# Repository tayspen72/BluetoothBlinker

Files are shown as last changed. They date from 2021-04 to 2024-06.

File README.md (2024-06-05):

Objective:
The goal of the project is to help myself become more familiar with the electronics design process. This includes:
* Schematic Design
* Component Selection
* PCB Layout
* Initial Board Bring-Up and Verification
* Firmware Development
* Evaluate Rust in an embedded microcontroller application

Plan
Build a PCB project with a similar purpose to a manufacturer evalutation kit with the following requirements:
* Bluetooth connectivity
* IO available with _reasonable_ function through peripherals
* Connectible to PC using USB-C
* Logging through UART when connected to PC

Conclusion:
The board design was completed and peer reviewed (by coworker)
Samples were ordered through PCB way and digikey for components
Samples were hand assembled (with blood sweat and tears)
Issue in the inline fuse, replaced with 0R resistor to advance in design
Board is functional, able to program and toggle LED using available IO
Bluetooth connectivity is pending..

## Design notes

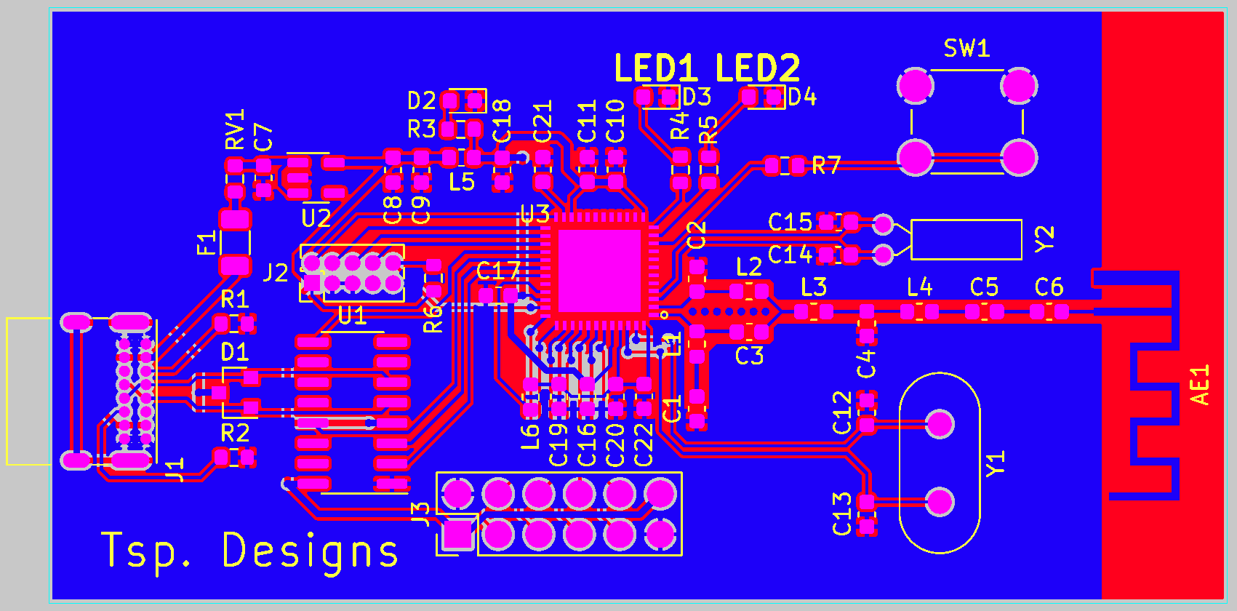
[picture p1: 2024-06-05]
BluetoothBlinker-PCB/BluetoothBlinkerPCB_Silkscreen.png

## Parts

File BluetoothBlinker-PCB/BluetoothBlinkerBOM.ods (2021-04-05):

Source:BluetoothBlinker-PCB.sch
Date:
Tool: Eescheme 5.1.9
Generator:
Component Count: | 51
Ref | Qnty | Value | Cmp name | Footprint | Description | Vendor
AE1, | 1 | Antenna | Antenna-Device | RF_Antenna:Texas_SWRA117D_2.4GHz_Right
C1, C2, C3, C4, C5, C6, C9, C10, C11, C16, C18, C20, C22, | 13 | 0.1uF | C | Capacitor_SMD:C_0603_1608Metric | Unpolarized capacitor
C7, C8, | 2 | 1.0uF | C | Capacitor_SMD:C_0603_1608Metric | Unpolarized capacitor
C12, C13, C14, C15, C21, | 5 | 12pF | C | Capacitor_SMD:C_0603_1608Metric | Unpolarized capacitor
C17, C19, | 2 | 22uF | C | Capacitor_SMD:C_0603_1608Metric | Unpolarized capacitor
D1, | 1 | SP0502BAHT | SP0502BAHT | Package_TO_SOT_SMD:SOT-23 | TVS Diode Array, 5.5V Standoff, 2 Channels, SOT-23 package
D2, | 1 | LED_GREEN | LED | LED_SMD:LED_0603_1608Metric | Light emitting diode
D3, D4, | 2 | LED_BLUE | LED | LED_SMD:LED_0603_1608Metric | Light emitting diode
F1, | 1 | Polyfuse | Polyfuse | Resistor_SMD:R_1206_3216Metric | Resettable fuse, polymeric positive temperature coefficient
J1, | 1 | USB_C_Receptacle_USB2.0 | USB_C_Receptacle_USB2.0 | Connector_USB:USB_C_Receptacle_GCT_USB4085 | USB 2.0-only Type-C Receptacle connector
J2, | 1 | Programming Connector | Conn_02x05_Odd_Even | Connector_PinHeader_1.27mm:PinHeader_2x05_P1.27mm_Vertical | Generic connector, double row, 02x05, odd/even pin numbering scheme (row 1 odd numbers, row 2 even numbers), script generated (kicad-library-utils/schlib/autogen/connector/)
J3, | 1 | Expansion Header | Conn_02x06_Odd_Even | Connector_PinHeader_2.54mm:PinHeader_2x06_P2.54mm_Vertical | Generic connector, double row, 02x06, odd/even pin numbering scheme (row 1 odd numbers, row 2 even numbers), script generated (kicad-library-utils/schlib/autogen/connector/)
L1, L2, L3, L4, | 4 | 2.4nH | L | Inductor_SMD:L_0603_1608Metric | Inductor
L5, L6, | 2 | 6.8uH | L | Inductor_SMD:L_0603_1608Metric | Inductor
R1, R2, | 2 | 5.1k | R_US | Resistor_SMD:R_0603_1608Metric | Resistor, US symbol
R3, R4, R5, R7, | 4 | 200R | R_US | Resistor_SMD:R_0603_1608Metric | Resistor, US symbol
R6, | 1 | 100k | R_US | Resistor_SMD:R_0603_1608Metric | Resistor, US symbol
RV1, | 1 | Varistor_US | Varistor_US | Resistor_SMD:R_0603_1608Metric | Voltage dependent resistor, US symbol
SW1, | 1 | SW_Push | SW_Push | Button_Switch_THT:SW_PUSH_6mm | Push button switch, generic, two pins
U1, | 1 | CH340C | CH340C | Package_SO:SOIC-16_3.9x9.9mm_P1.27mm | USB serial converter, UART, SOIC-16
U2, | 1 | TLV75533PDBV | TLV75533PDBV | Package_TO_SOT_SMD:SOT-23-5 | 500mA Low Dropout Voltage Regulator, Fixed Output 3.3V, SOT-23-5
U3, | 1 | CC2642R | CC2642R-MySymbols | MyFootprints:CC2642R
Y1, | 1 | 48MHz | Crystal | Crystal:Crystal_HC49-U_Vertical | Two pin crystal
Y2, | 1 | 32.768kHz | Crystal | Crystal:Crystal_C26-LF_D2.1mm_L6.5mm_Horizontal | Two pin crystal

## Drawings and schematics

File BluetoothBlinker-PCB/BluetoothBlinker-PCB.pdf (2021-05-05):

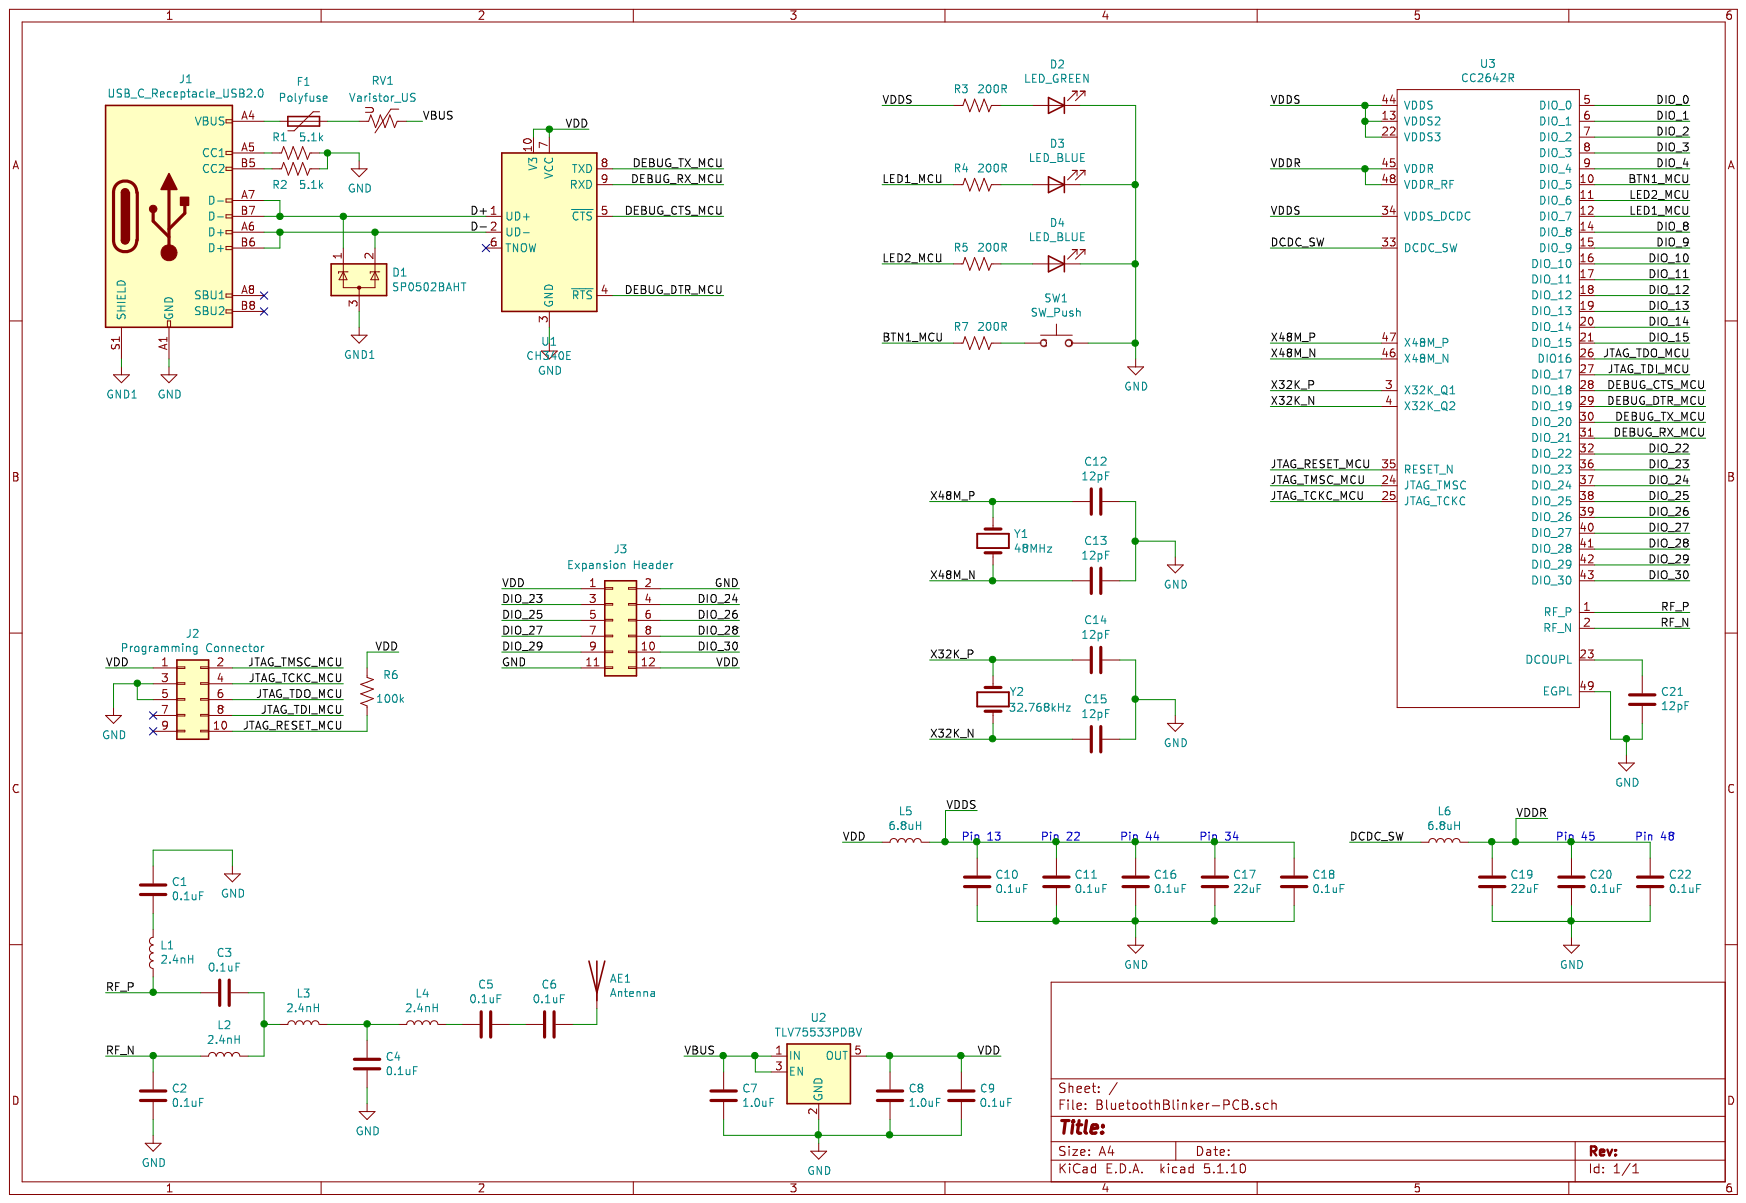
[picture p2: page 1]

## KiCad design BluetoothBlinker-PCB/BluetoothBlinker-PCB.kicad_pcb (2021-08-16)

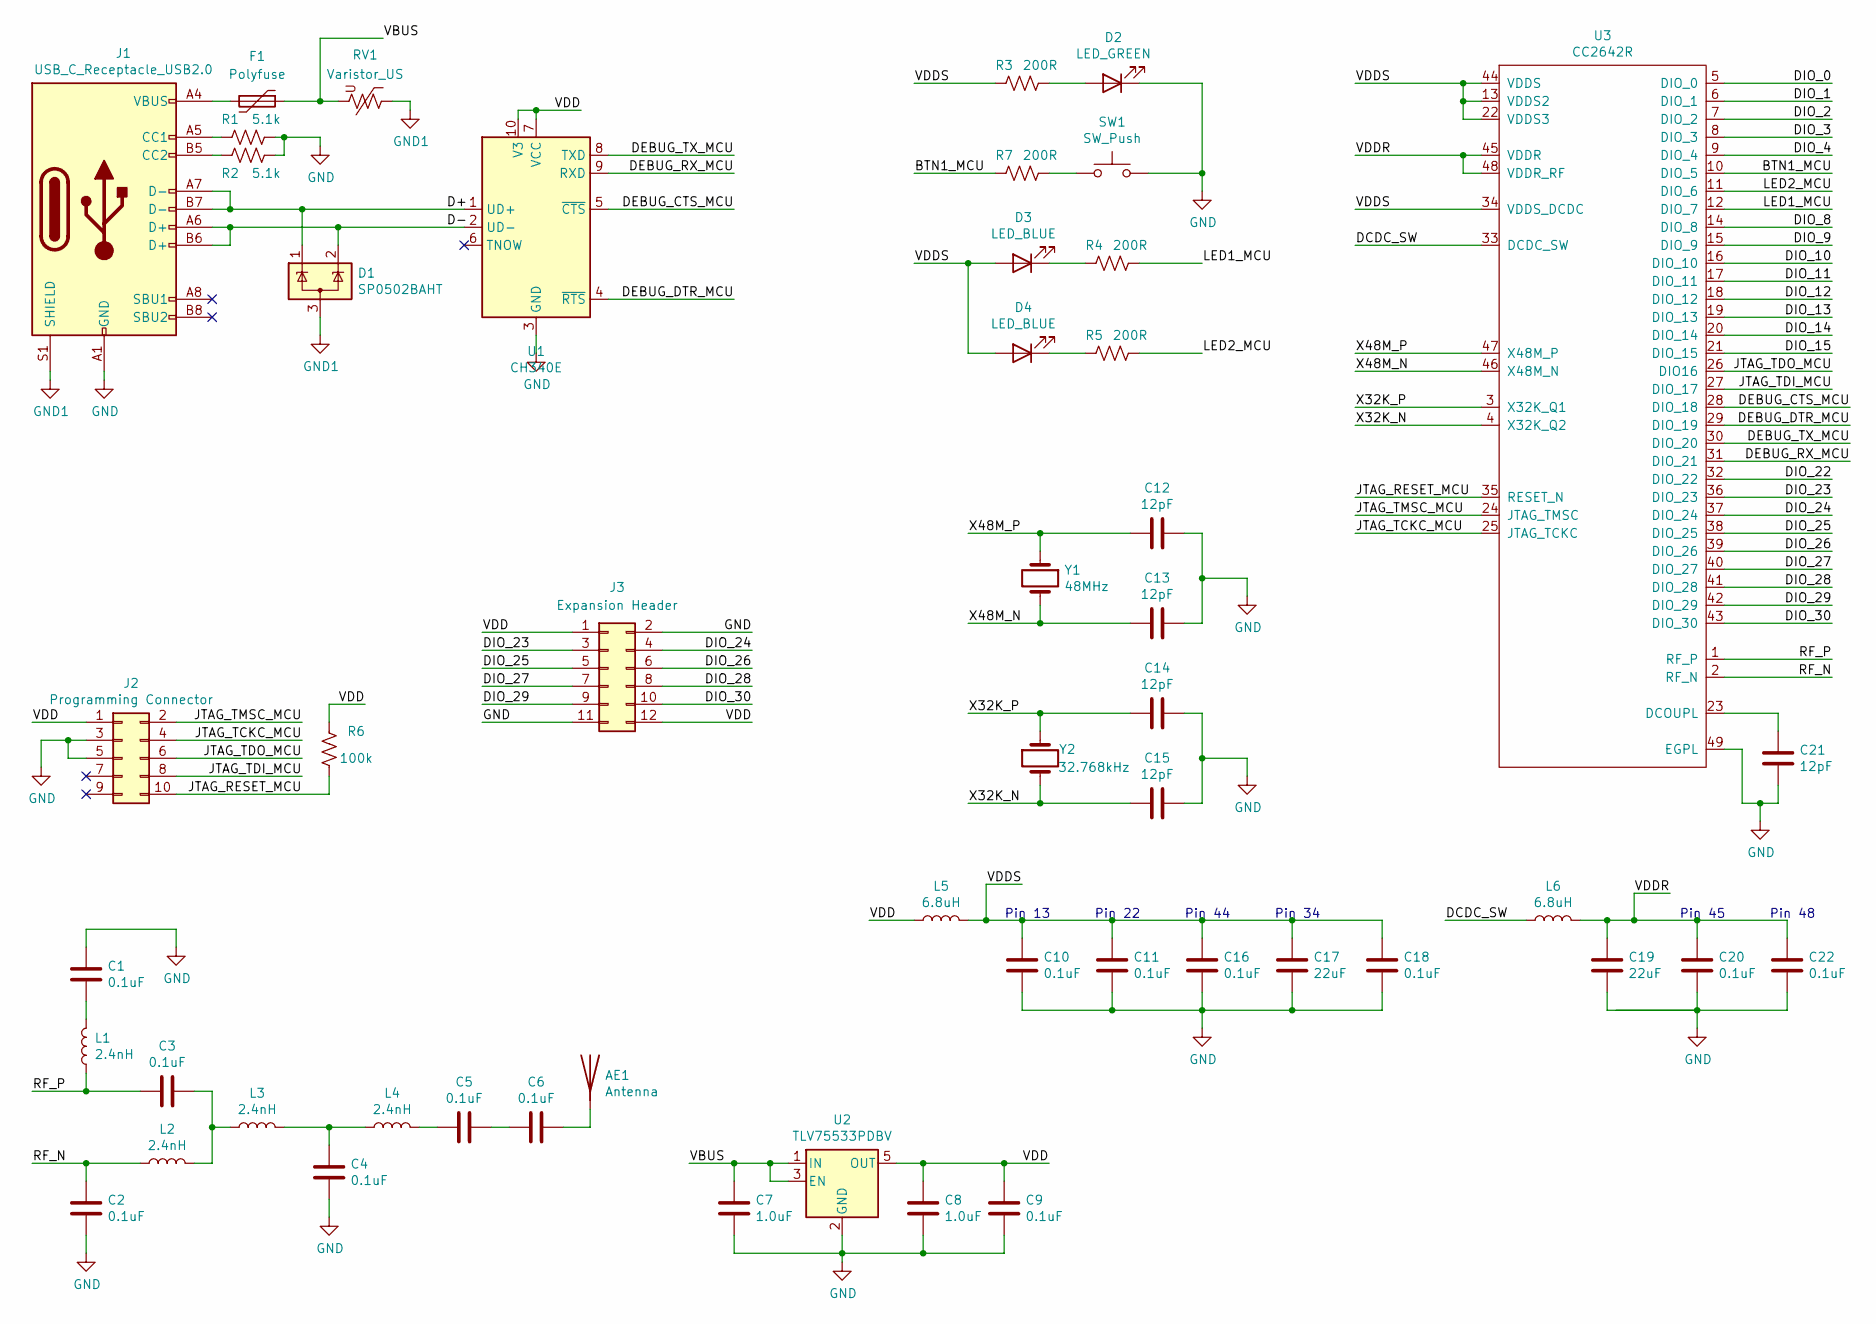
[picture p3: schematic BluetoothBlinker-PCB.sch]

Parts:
AE1: Antenna; Texas_SWRA117D_2.4GHz_Right
C1, C2, C3, C4, C5, C6, C9, C10, C11, C16, C18, C20, C22: 0.1uF; C_0603_1608Metric
C7, C8: 1.0uF; C_0603_1608Metric
C12, C13, C14, C15, C21: 12pF; C_0603_1608Metric
C17, C19: 22uF; C_0603_1608Metric
D1: SP0502BAHT; SOT-23
D2: LED_GREEN; LED_0603_1608Metric
D3, D4: LED_BLUE; LED_0603_1608Metric
F1: Polyfuse; R_1206_3216Metric
J1: USB_C_Receptacle_USB2.0; USB_C_Receptacle_GCT_USB4085
J2: Programming Connector; PinHeader_2x05_P1.27mm_Vertical
J3: Expansion Header; PinHeader_2x06_P2.54mm_Vertical
L1, L2, L3, L4: 2.4nH; L_0603_1608Metric
L5, L6: 6.8uH; L_0603_1608Metric
R1, R2: 5.1k; R_0603_1608Metric
R3, R4, R5, R7: 200R; R_0603_1608Metric
R6: 100k; R_0603_1608Metric
RV1: Varistor_US; R_0603_1608Metric
SW1: SW_Push; SW_PUSH_6mm
U1: CH340E; MSOP-10_3x3mm_P0.5mm
U2: TLV75533PDBV; SOT-23-5
U3: CC2642R
Y1: 48MHz; Crystal_HC49-U_Vertical
Y2: 32.768kHz; Crystal_C26-LF_D2.1mm_L6.5mm_Horizontal

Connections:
/BTN1_MCU: R7.1, U3.10 (DIO_5)
/D+: D1.1 (K), J1.A7 (D-), J1.B7 (D-), U1.1 (UD+)
/D-: D1.2 (K), J1.A6 (D+), J1.B6 (D+), U1.2 (UD-)
/DCDC_SW: L6.1, U3.33 (DCDC_SW)
/DEBUG_CTS_MCU: U1.5 (~CTS), U3.28 (DIO_18)
/DEBUG_DTR_MCU: U1.4 (~RTS), U3.29 (DIO_19)
/DEBUG_RX_MCU: U1.9 (RXD), U3.31 (DIO_21)
/DEBUG_TX_MCU: U1.8 (TXD), U3.30 (DIO_20)
/DIO_0: U3.5 (DIO_0)
/DIO_1: U3.6 (DIO_1)
/DIO_2: U3.7 (DIO_2)
/DIO_3: U3.8 (DIO_3)
/DIO_4: U3.9 (DIO_4)
/DIO_8: U3.14 (DIO_8)
/DIO_9: U3.15 (DIO_9)
/DIO_10: U3.16 (DIO_10)
/DIO_11: U3.17 (DIO_11)
/DIO_12: U3.18 (DIO_12)
/DIO_13: U3.19 (DIO_13)
/DIO_14: U3.20 (DIO_14)
/DIO_15: U3.21 (DIO_15)
/DIO_22: U3.32 (DIO_22)
/DIO_23: J3.3, U3.36 (DIO_23)
/DIO_24: J3.4, U3.37 (DIO_24)
/DIO_25: J3.5, U3.38 (DIO_25)
/DIO_26: J3.6, U3.39 (DIO_26)
/DIO_27: J3.7, U3.40 (DIO_27)
/DIO_28: J3.8, U3.41 (DIO_28)
/DIO_29: J3.9, U3.42 (DIO_29)
/DIO_30: J3.10, U3.43 (DIO_30)
/JTAG_RESET_MCU: J2.10, R6.1, U3.35 (RESET_N)
/JTAG_TCKC_MCU: J2.4, U3.25 (JTAG_TCKC)
/JTAG_TDI_MCU: J2.8, U3.27 (DIO_17)
/JTAG_TDO_MCU: J2.6, U3.26 (DIO16)
/JTAG_TMSC_MCU: J2.2, U3.24 (JTAG_TMSC)
/LED1_MCU: R4.2, U3.12 (DIO_7)
/LED2_MCU: R5.2, U3.11 (DIO_6)
/RF_N: C2.1, L2.1, U3.2 (RF_N)
/RF_P: C3.2, L1.1, U3.1 (RF_P)
/VBUS: C7.1, F1.1, RV1.2, U2.1 (IN), U2.3 (EN)
/VDD: C8.1, C9.1, J2.1, J3.1, J3.12, L5.1, R6.2, U1.7 (VCC), U1.10 (V3), U2.5 (OUT)
/VDDR: C19.1, C20.1, C22.1, L6.2, U3.45 (VDDR), U3.48 (VDDR_RF)
/VDDS: C10.1, C11.1, C16.1, C17.1, C18.1, D3.2 (A), D4.2 (A), L5.2, R3.1, U3.13 (VDDS2), U3.22 (VDDS3), U3.34 (VDDS_DCDC), U3.44 (VDDS)
/X32K_N: C15.2, U3.4 (X32K_Q2), Y2.2
/X32K_P: C14.2, U3.3 (X32K_Q1), Y2.1
/X48M_N: C13.2, U3.46 (X48M_N), Y1.2
/X48M_P: C12.2, U3.47 (X48M_P), Y1.1
GND: C1.2, C2.2, C4.2, C7.2, C8.2, C9.2, C10.2, C11.2, C12.1, C13.1, C14.1, C15.1, C16.2, C17.2, C18.2, C19.2, C20.2, C21.1, C22.2, D2.1 (K), J1.A1 (GND), J1.A12 (GND), J1.B1 (GND), J1.B12 (GND), J2.3, J2.5, J3.2, J3.11, R1.1, R2.1, SW1.2, U1.3 (GND), U2.2 (GND), U3.49 (EGPL)
GND1: D1.3 (A), J1.S1 (SHIELD), RV1.1
unnamed: AE1.1, C6.1
unnamed: C1.1, L1.2
unnamed: C3.1, L2.2, L3.1
unnamed: C4.1, L3.2, L4.1
unnamed: C5.1, C6.2
unnamed: C5.2, L4.2
unnamed: C21.2, U3.23 (DCOUPL)
unnamed: D2.2 (A), R3.2
unnamed: D3.1 (K), R4.1
unnamed: D4.1 (K), R5.1
unnamed: F1.2, J1.A4 (VBUS), J1.A9 (VBUS), J1.B4 (VBUS), J1.B9 (VBUS)
unnamed: J1.A5 (CC1), R1.2
unnamed: J1.B5 (CC2), R2.2
unnamed: R7.2, SW1.1

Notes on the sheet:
Pin 45
Pin 48
Pin 13
Pin 22
Pin 44
Pin 34

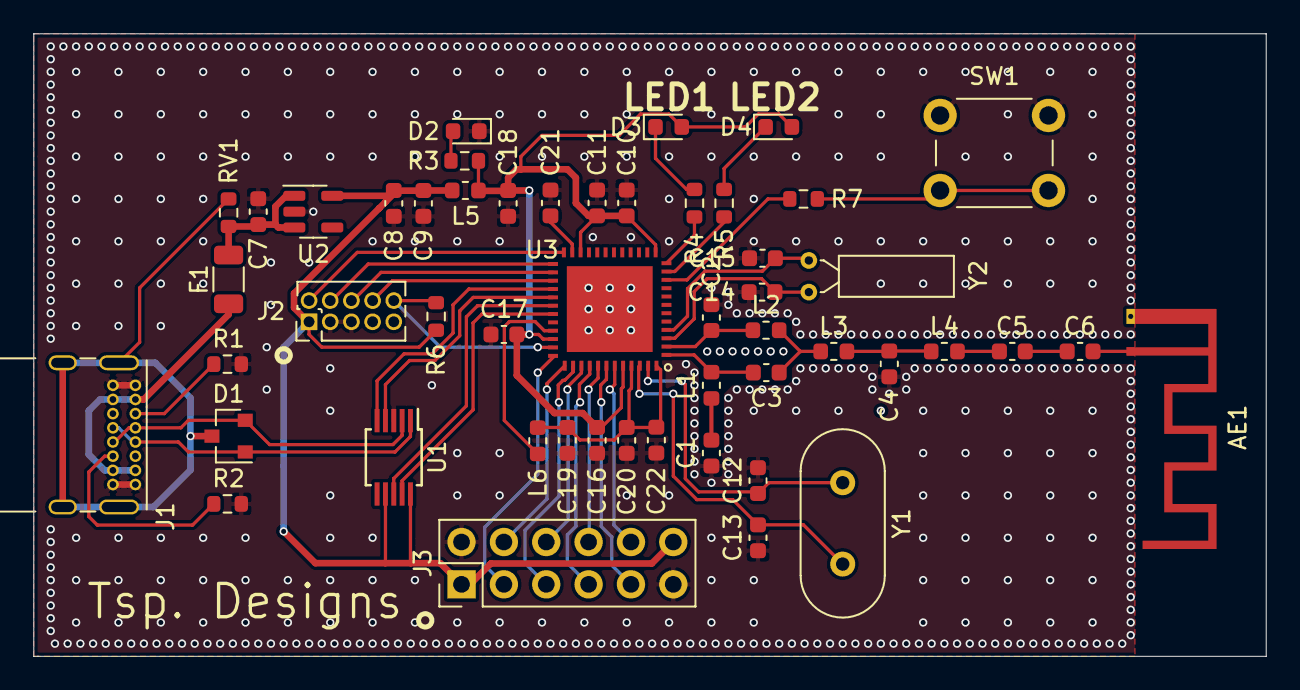
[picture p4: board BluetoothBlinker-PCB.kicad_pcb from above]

Board: 2 copper layers, 73.9 x 37.3 mm, 51 parts (0 on the bottom side), 49 nets.

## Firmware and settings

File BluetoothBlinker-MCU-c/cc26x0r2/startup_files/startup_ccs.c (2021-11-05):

/******************************************************************************
*  Filename:       startup_ccs.c
*  Revised:        $Date: 2017-02-03 19:16:24 +0100 (Fri, 03 Feb 2017) $
*  Revision:       $Revision: 17634 $
*
*  Description:    Startup code for CC26x0 rev2 device family for use with CCS.
*
*  Copyright (C) 2017 Texas Instruments Incorporated - http://www.ti.com/
*
*
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
*    Redistributions of source code must retain the above copyright
*    notice, this list of conditions and the following disclaimer.
*
*    Redistributions in binary form must reproduce the above copyright
*    notice, this list of conditions and the following disclaimer in the
*    documentation and/or other materials provided with the distribution.
*
*    Neither the name of Texas Instruments Incorporated nor the names of
*    its contributors may be used to endorse or promote products derived
*    from this software without specific prior written permission.
*
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
******************************************************************************/


//*****************************************************************************
//
// Check if compiler is CCS
//
//*****************************************************************************
#if !(defined(__TI_COMPILER_VERSION__))
#error "startup_ccs.c: Unsupported compiler!"
#endif

#include "../inc/hw_types.h"
#include "../driverlib/setup.h"


//*****************************************************************************
//
//! Forward declaration of the reset ISR and the default fault handlers.
//
//*****************************************************************************
void        ResetISR( void );
static void NmiSR( void );
static void FaultISR( void );
static void IntDefaultHandler( void );
extern int  main(void);


//*****************************************************************************
//
//! The entry point for the application startup code.
//
//*****************************************************************************
extern void _c_int00(void);


//*****************************************************************************
//
// CCS: Linker variable that marks the top of the stack.
//
//*****************************************************************************
extern unsigned long __STACK_END;


//! The vector table. Note that the proper constructs must be placed on this to
//! ensure that it ends up at physical address 0x0000.0000 or at the start of
//! the program if located at a start address other than 0.
//
//*****************************************************************************
#pragma DATA_SECTION(g_pfnVectors, ".intvecs")
void (* const g_pfnVectors[])(void) =
{
    (void (*)(void))((unsigned long)&__STACK_END),
                                            //  0 The initial stack pointer
    ResetISR,                               //  1 The reset handler
    NmiSR,                                  //  2 The NMI handler
    FaultISR,                               //  3 The hard fault handler
    IntDefaultHandler,                      //  4 The MPU fault handler
    IntDefaultHandler,                      //  5 The bus fault handler
    IntDefaultHandler,                      //  6 The usage fault handler
    0,                                      //  7 Reserved
    0,                                      //  8 Reserved
    0,                                      //  9 Reserved
    0,                                      // 10 Reserved
    IntDefaultHandler,                      // 11 SVCall handler
    IntDefaultHandler,                      // 12 Debug monitor handler
    0,                                      // 13 Reserved
    IntDefaultHandler,                      // 14 The PendSV handler
    IntDefaultHandler,                      // 15 The SysTick handler
    //--- External interrupts ---
    IntDefaultHandler,                      // 16 AON edge detect
    IntDefaultHandler,                      // 17 I2C
    IntDefaultHandler,                      // 18 RF Core Command & Packet Engine 1
    IntDefaultHandler,                      // 19 Reserved
    IntDefaultHandler,                      // 20 AON RTC
    IntDefaultHandler,                      // 21 UART0 Rx and Tx
    IntDefaultHandler,                      // 22 AUX software event 0
    IntDefaultHandler,                      // 23 SSI0 Rx and Tx
    IntDefaultHandler,                      // 24 SSI1 Rx and Tx
    IntDefaultHandler,                      // 25 RF Core Command & Packet Engine 0
    IntDefaultHandler,                      // 26 RF Core Hardware
    IntDefaultHandler,                      // 27 RF Core Command Acknowledge
    IntDefaultHandler,                      // 28 I2S
    IntDefaultHandler,                      // 29 AUX software event 1
    IntDefaultHandler,                      // 30 Watchdog timer
    IntDefaultHandler,                      // 31 Timer 0 subtimer A
    IntDefaultHandler,                      // 32 Timer 0 subtimer B
    IntDefaultHandler,                      // 33 Timer 1 subtimer A
    IntDefaultHandler,                      // 34 Timer 1 subtimer B
    IntDefaultHandler,                      // 35 Timer 2 subtimer A
    IntDefaultHandler,                      // 36 Timer 2 subtimer B
    IntDefaultHandler,                      // 37 Timer 3 subtimer A
    IntDefaultHandler,                      // 38 Timer 3 subtimer B
    IntDefaultHandler,                      // 39 Crypto Core Result available
    IntDefaultHandler,                      // 40 uDMA Software
    IntDefaultHandler,                      // 41 uDMA Error
    IntDefaultHandler,                      // 42 Flash controller
    IntDefaultHandler,                      // 43 Software Event 0
    IntDefaultHandler,                      // 44 AUX combined event
    IntDefaultHandler,                      // 45 AON programmable 0
    IntDefaultHandler,                      // 46 Dynamic Programmable interrupt
                                            //    source (Default: PRCM)
    IntDefaultHandler,                      // 47 AUX Comparator A
    IntDefaultHandler,                      // 48 AUX ADC new sample or ADC DMA
                                            //    done, ADC underflow, ADC overflow
    IntDefaultHandler                       // 49 TRNG event
};


//*****************************************************************************
//
//! This is the code that gets called when the processor first starts execution
//! following a reset event. Only the absolutely necessary set is performed,
//! after which the application supplied entry() routine is called. Any fancy
//! actions (such as making decisions based on the reset cause register, and
//! resetting the bits in that register) are left solely in the hands of the
//! application.
//
//*****************************************************************************
void
ResetISR(void)
{
    //
    // Final trim of device
    //
    SetupTrimDevice();

    //
    // Jump to the CCS C Initialization Routine.
    //
    __asm("    .global _c_int00\n"
            "    b.w     _c_int00");

    //
    // If we ever return signal Error
    //
    FaultISR();
}

//*****************************************************************************
//
//! This is the code that gets called when the processor receives a NMI. This
//! simply enters an infinite loop, preserving the system state for examination
//! by a debugger.
//
//*****************************************************************************
static void
NmiSR(void)
{
    //
    // Enter an infinite loop.
    //
    while(1)
    {
    }
}

//*****************************************************************************
//
//! This is the code that gets called when the processor receives a fault
//! interrupt. This simply enters an infinite loop, preserving the system state
//! for examination by a debugger.
//
//*****************************************************************************
static void
FaultISR(void)
{
    //
    // Enter an infinite loop.
    //
    while(1)
    {
    }
}


//*****************************************************************************
//
//! This is the code that gets called when the processor receives an unexpected
//! interrupt. This simply enters an infinite loop, preserving the system state
//! for examination by a debugger.
//
//*****************************************************************************
static void
IntDefaultHandler(void)
{
    //
    // Go into an infinite loop.
    //
    while(1)
    {
    }
}

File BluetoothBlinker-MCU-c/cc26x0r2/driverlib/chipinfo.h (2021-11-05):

/******************************************************************************
*  Filename:       chipinfo.h
*  Revised:        2018-06-18 10:26:12 +0200 (Mon, 18 Jun 2018)
*  Revision:       52189
*
*  Description:    Collection of functions returning chip information.
*
*  Copyright (c) 2015 - 2017, Texas Instruments Incorporated
*  All rights reserved.
*
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
*  3) Neither the name of the ORGANIZATION nor the names of its contributors may
*     be used to endorse or promote products derived from this software without
*     specific prior written permission.
*
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
******************************************************************************/

//*****************************************************************************
//
//! \addtogroup system_control_group
//! @{
//! \addtogroup ChipInfo
//! @{
//
//*****************************************************************************

#ifndef __CHIP_INFO_H__
#define __CHIP_INFO_H__

//*****************************************************************************
//
// If building with a C++ compiler, make all of the definitions in this header
// have a C binding.
//
//*****************************************************************************
#ifdef __cplusplus
extern "C"
{
#endif

#include <stdint.h>
#include <stdbool.h>
#include "../inc/hw_types.h"
#include "../inc/hw_memmap.h"
#include "../inc/hw_fcfg1.h"

//*****************************************************************************
//
// Support for DriverLib in ROM:
// This section renames all functions that are not "static inline", so that
// calling these functions will default to implementation in flash. At the end
// of this file a second renaming will change the defaults to implementation in
// ROM for available functions.
//
// To force use of the implementation in flash, e.g. for debugging:
// - Globally: Define DRIVERLIB_NOROM at project level
// - Per function: Use prefix "NOROM_" when calling the function
//
//*****************************************************************************
#if !defined(DOXYGEN)
    #define ChipInfo_GetSupportedProtocol_BV NOROM_ChipInfo_GetSupportedProtocol_BV
    #define ChipInfo_GetPackageType         NOROM_ChipInfo_GetPackageType
    #define ChipInfo_GetChipType            NOROM_ChipInfo_GetChipType
    #define ChipInfo_GetChipFamily          NOROM_ChipInfo_GetChipFamily
    #define ChipInfo_GetHwRevision          NOROM_ChipInfo_GetHwRevision
    #define ThisLibraryIsFor_CC26x0R2_HaltIfViolated NOROM_ThisLibraryIsFor_CC26x0R2_HaltIfViolated
#endif

//*****************************************************************************
//
//! \brief Enumeration identifying the protocols supported.
//!
//! \note
//! This is a bit vector enumeration that indicates supported protocols.
//! E.g: 0x06 means that the chip supports both BLE and IEEE 802.15.4
//
//*****************************************************************************
typedef enum {
   PROTOCOL_Unknown          = 0   , //!< None of the known protocols are supported.
   PROTOCOLBIT_BLE           = 0x02, //!< Bit[1] set, indicates that Bluetooth Low Energy is supported.
   PROTOCOLBIT_IEEE_802_15_4 = 0x04, //!< Bit[2] set, indicates that IEEE 802.15.4 is supported.
   PROTOCOLBIT_Proprietary   = 0x08  //!< Bit[3] set, indicates that proprietary protocols are supported.
} ProtocolBitVector_t;

//*****************************************************************************
//
//! \brief Returns bit vector showing supported protocols.
//!
//! \return
//! Returns \ref ProtocolBitVector_t which is a bit vector indicating supported protocols.
//
//*****************************************************************************
extern ProtocolBitVector_t ChipInfo_GetSupportedProtocol_BV( void );

//*****************************************************************************
//
//! \brief Returns true if the chip supports the BLE protocol.
//!
//! \return
//! Returns \c true if supporting the BLE protocol, \c false otherwise.
//
//*****************************************************************************
__STATIC_INLINE bool
ChipInfo_SupportsBLE( void )
{
   return (( ChipInfo_GetSupportedProtocol_BV() & PROTOCOLBIT_BLE ) != 0 );
}

//*****************************************************************************
//
//! \brief Returns true if the chip supports the IEEE 802.15.4 protocol.
//!
//! \return
//! Returns \c true if supporting the IEEE 802.15.4 protocol, \c false otherwise.
//
//*****************************************************************************
__STATIC_INLINE bool
ChipInfo_SupportsIEEE_802_15_4( void )
{
   return (( ChipInfo_GetSupportedProtocol_BV() & PROTOCOLBIT_IEEE_802_15_4 ) != 0 );
}
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

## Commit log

2021-04-05 Added BOM for v1.0
    [BluetoothBlinkerBOM.ods]
2021-05-05 Update to new USB Uart and generate PDF
    [BluetoothBlinker-PCB.kicad_pcb, BluetoothBlinker-PCB.sch]
2021-05-07 Initial bindings and config
    [main.rs]
2021-08-16 Minor updates
    [BluetoothBlinker-PCB.kicad_pcb, BluetoothBlinker-PCB.sch]
